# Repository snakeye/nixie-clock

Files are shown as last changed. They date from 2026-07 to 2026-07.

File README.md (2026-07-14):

# Nixie Clock

An ESP32-C3 powered Nixie clock built around custom KiCad hardware and Arduino firmware.

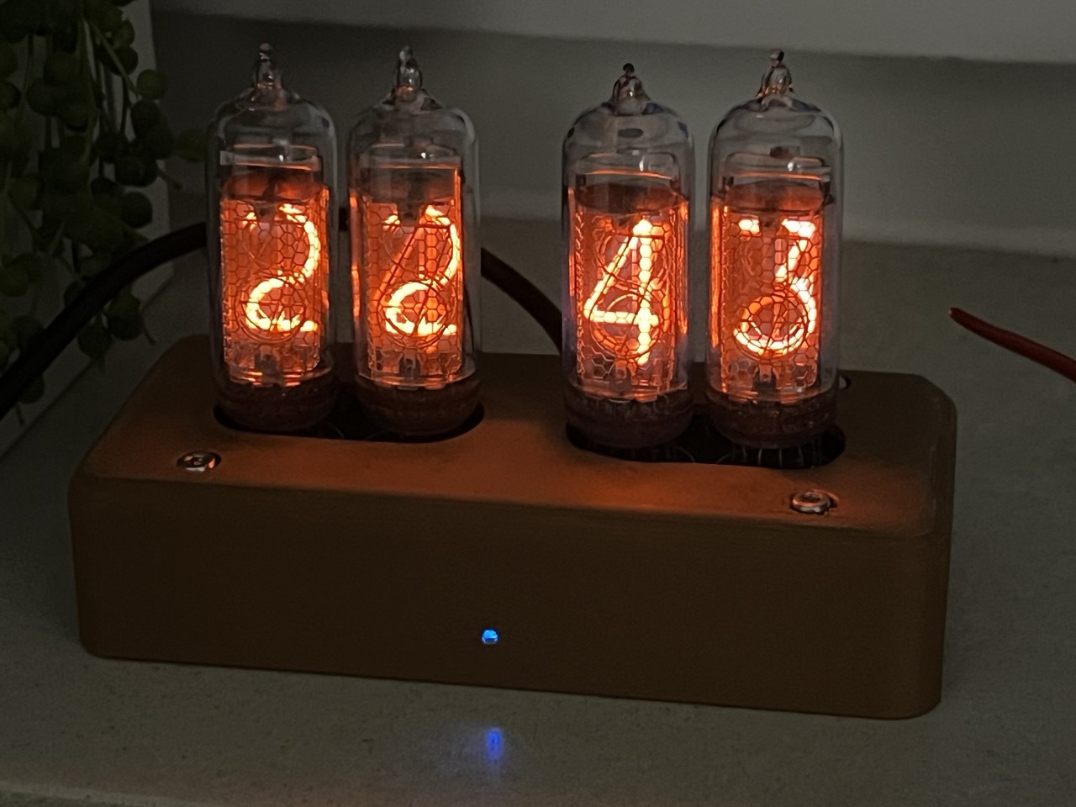
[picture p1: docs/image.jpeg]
Assembled Nixie clock


## Boards

### Main board

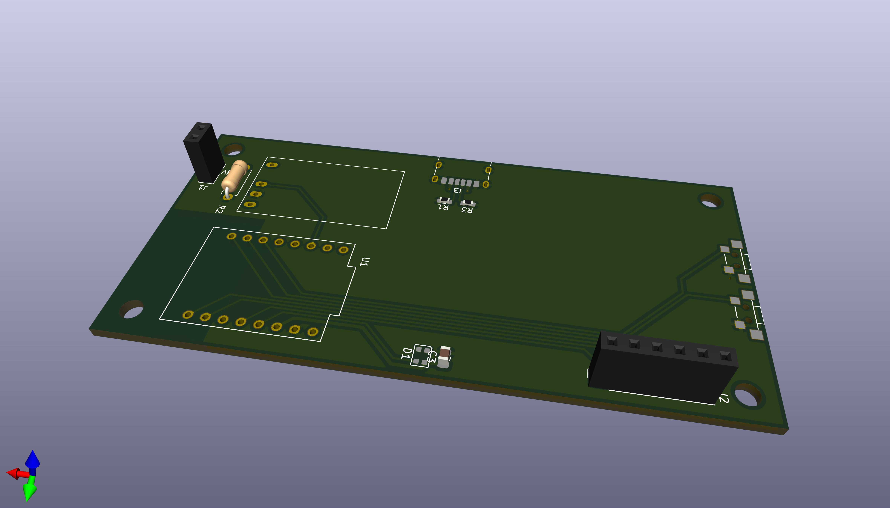
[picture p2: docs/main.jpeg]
Main board in KiCad


### Indicator board

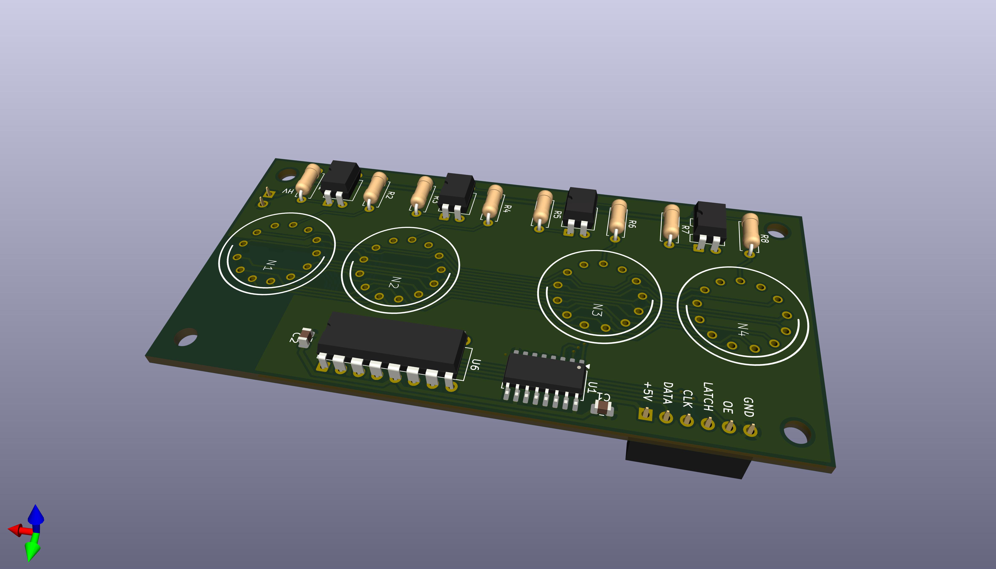
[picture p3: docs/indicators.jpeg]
Indicator board in KiCad


## What this is

This repository contains the hardware and firmware for a four-digit Nixie clock.
It uses Wi-Fi to sync time from NTP, drives the tubes with a multiplexed display stage, and keeps the high-voltage supply disabled until the clock has a valid time.

## Features

- Wi-Fi time sync via NTP
- Automatic high-voltage safety control
- OTA firmware updates
- Manual cathode cleaning from a button long-press
- Automatic daily cathode cleaning at midnight
- KiCad hardware for the main clock board and indicator board

## Key components

- IN-14 Nixie tubes
- 155ИД1 high-voltage digit driver
- ESP32-C3 SuperMini module
- 74HC595 shift register
- TLP627 optocouplers
- Nixie Tube Boost Converter module
- WS2812B RGB status LED
- USB-C power input
- Two push buttons

### High-voltage boost module

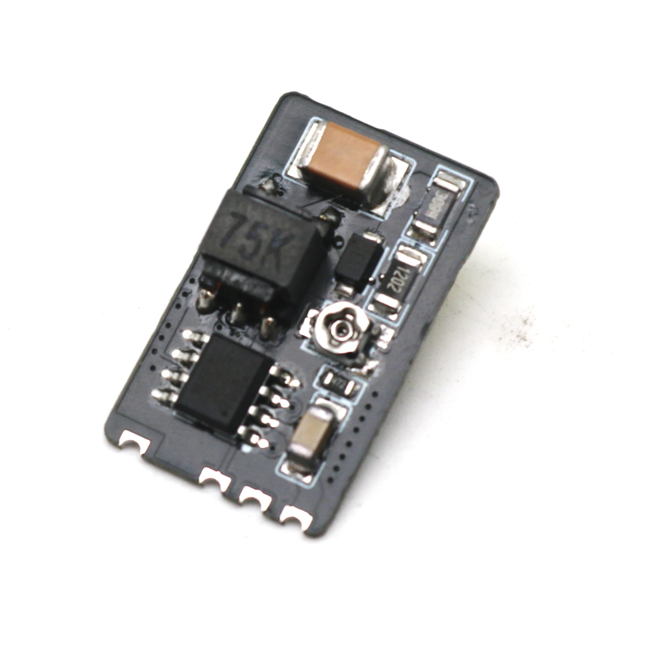
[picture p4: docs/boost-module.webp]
Boost converter module used in the build


I've used this particular module found on AliExpress. It features voltage adjustment. Other modules should also work, but they'll require proper wiring. 

## How it works

The firmware boots in a safe state with the display blanked and the high-voltage rail off.
After Wi-Fi connects and NTP provides a valid time, the clock enables the high-voltage section and starts showing the current time.

When a successful sync happens, the firmware opens a short OTA maintenance window. If an upload starts, the high-voltage rail is disabled while the update is in progress.

Button 1 has a long-press action that starts cathode cleaning manually. The same cleaning routine also runs automatically once per day when the clock reaches midnight.

## Repository layout

- `firmware/` - PlatformIO project for the ESP32-C3
- `hardware/main/` - main KiCad project for the clock board
- `hardware/indicators/` - indicator-board KiCad project
- `docs/` - photos and other documentation assets

## Firmware setup

1. Open `firmware/` in PlatformIO or your preferred VS Code setup.
2. Copy `firmware/src/config.h.example` to `firmware/src/config.h`.
3. Fill in your Wi-Fi SSID and password.
4. Build and upload the `esp32c3` environment.

The firmware is configured for the `esp32-c3-devkitm-1` board.

## Notes

- The clock currently uses a CET/CEST timezone definition in firmware.
- The firmware hostname is `nixie-clock`.
- `firmware/src/config.h` is ignored by Git so local Wi-Fi credentials stay machine-specific.

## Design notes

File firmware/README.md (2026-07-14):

# Nixie Clock Firmware

Firmware for the ESP32-based nixie clock.

## How it works

- On boot the firmware forces the outputs into a safe state.
- It connects to WiFi, configures NTP, and waits for valid time.
- Once time is valid, high voltage is enabled and the display starts multiplexing `HH:MM`.
- WiFi is shut down after sync unless the OTA maintenance window is active.
- During OTA the display is blanked and high voltage stays off.

## Main pieces

- `ClockTime` handles WiFi, NTP, timezone, and time validity.
- `NixieDisplay` owns the display buffer and multiplexing.
- `NixieSafetyController` keeps display and high voltage changes safe.
- `ClockDisplay` updates the shown time once per minute.
- `StatusLed` shows boot, waiting, sync, and OTA states.
- `OtaMaintenance` opens a short OTA window after sync.
- `CathodeCleaning` runs the anti-poisoning cycle at midnight and on long press.

## Controls

- Button 1 long press starts cathode cleaning.

## Configuration

- WiFi credentials currently live in `src/config.h`.
- Debug logging is enabled with the `DEBUG_LOG` build flag.

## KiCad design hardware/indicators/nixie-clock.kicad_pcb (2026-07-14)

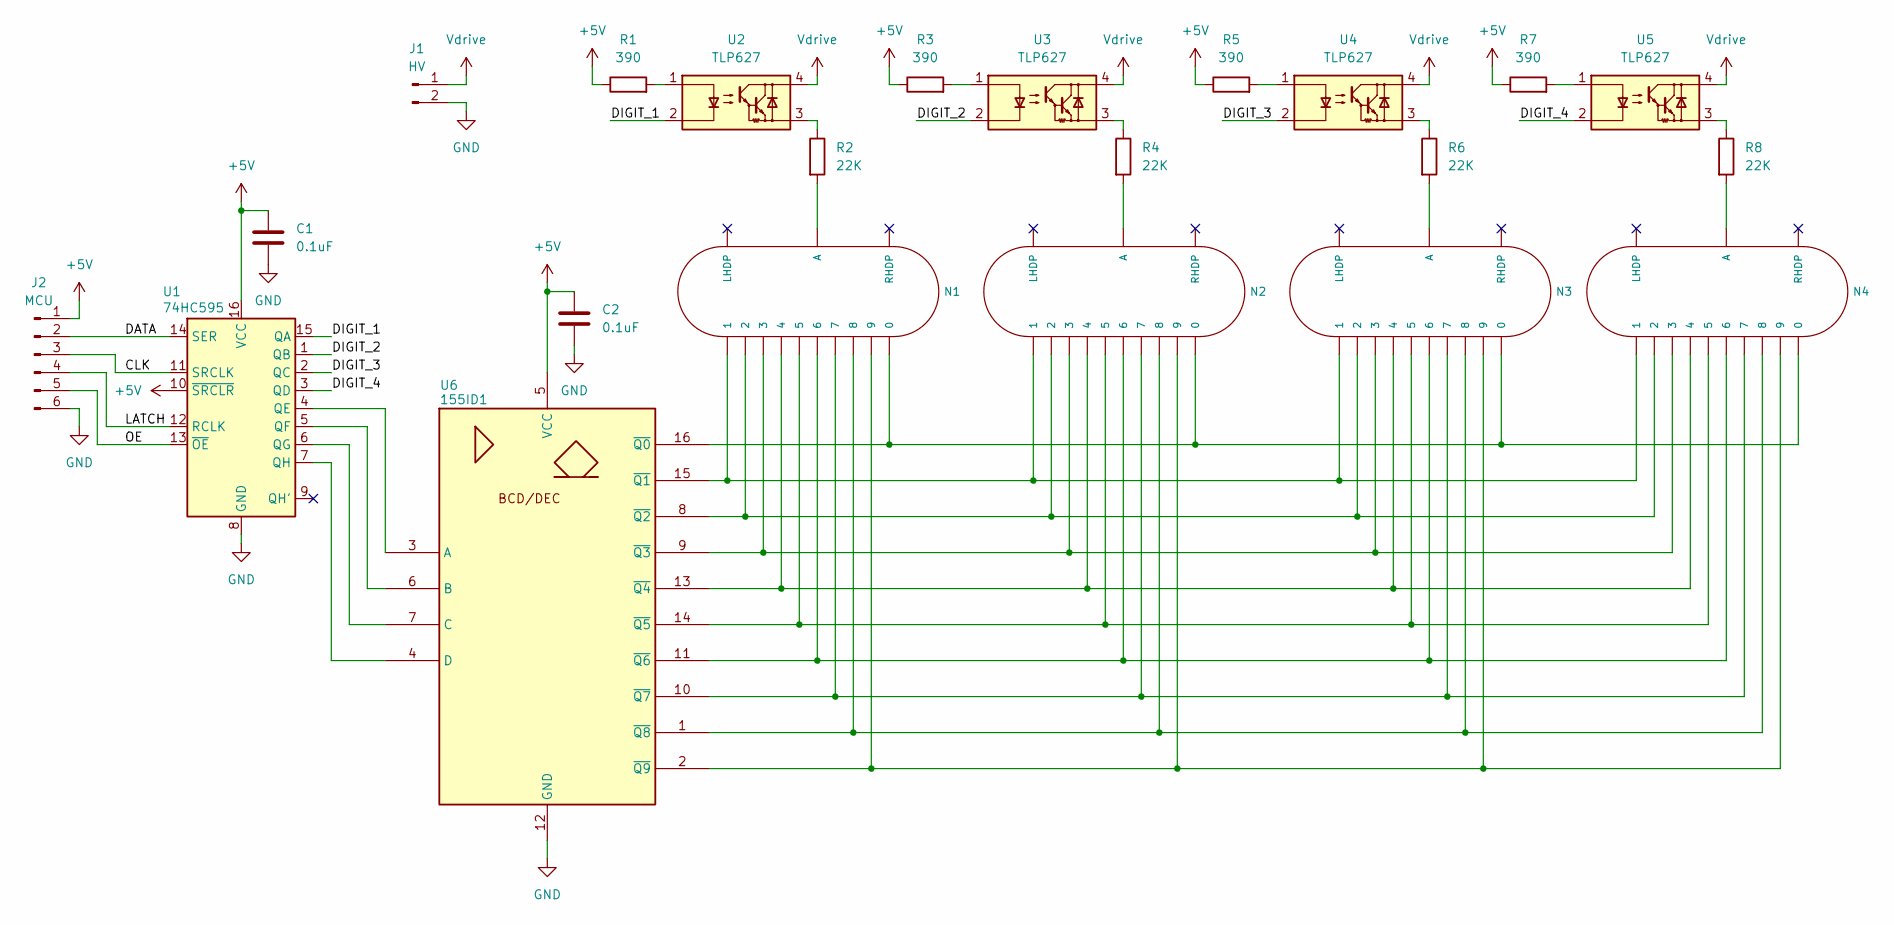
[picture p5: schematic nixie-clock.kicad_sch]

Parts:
C1, C2: 0.1uF; C_0805_2012Metric
J1: HV; PinSocket_1x02_P2.54mm_Vertical
J2: MCU; PinSocket_1x06_P2.54mm_Vertical
N1, N2, N3, N4: IN-14; nixies-us-IN-14
R1, R3, R5, R7: 390; R_Axial_DIN0207_L6.3mm_D2.5mm_P7.62mm_Horizontal
R2, R4, R6, R8: 22K; R_Axial_DIN0207_L6.3mm_D2.5mm_P7.62mm_Horizontal
U1: 74HC595; SOP-16_4.4x10.4mm_P1.27mm
U2, U3, U4, U5: TLP627; DIP-4_W7.62mm
U6: 155ID1; DIP-16_W7.62mm

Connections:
+5V: C1.1, C2.1, J2.1, R1.1, R3.1, R5.1, R7.1, U1.10 (~SRCLR), U1.16 (VCC), U6.5 (VCC)
/CLK: J2.3, U1.11 (SRCLK)
/DATA: J2.2, U1.14 (SER)
/DIGIT_1: U1.15 (QA), U2.2
/DIGIT_2: U1.1 (QB), U3.2
/DIGIT_3: U1.2 (QC), U4.2
/DIGIT_4: U1.3 (QD), U5.2
/LATCH: J2.4, U1.12 (RCLK)
/OE: J2.5, U1.13 (~OE)
GND: C1.2, C2.2, J1.2, J2.6, U1.8 (GND), U6.12 (GND)
unnamed: N1.A, R2.2
unnamed: N2.A, R4.2
unnamed: N3.A, R6.2
unnamed: N4.A, R8.2
unnamed: R1.2, U2.1
unnamed: R2.1, U2.3
unnamed: R3.2, U3.1
unnamed: R4.1, U3.3
unnamed: R5.2, U4.1
unnamed: R6.1, U4.3
unnamed: R7.2, U5.1
unnamed: R8.1, U5.3
unnamed: U1.4 (QE), U6.3 (A)
unnamed: U1.5 (QF), U6.6 (B)
unnamed: U1.6 (QG), U6.7 (C)
unnamed: U1.7 (QH), U6.4 (D)
unnamed: N1.0, N2.0, N3.0, N4.0, U6.16 (~Q0)
unnamed: N1.1, N2.1, N3.1, N4.1, U6.15 (~Q1)
unnamed: N1.2, N2.2, N3.2, N4.2, U6.8 (~Q2)
unnamed: N1.3, N2.3, N3.3, N4.3, U6.9 (~Q3)
unnamed: N1.4, N2.4, N3.4, N4.4, U6.13 (~Q4)
unnamed: N1.5, N2.5, N3.5, N4.5, U6.14 (~Q5)
unnamed: N1.6, N2.6, N3.6, N4.6, U6.11 (~Q6)
unnamed: N1.7, N2.7, N3.7, N4.7, U6.10 (~Q7)
unnamed: N1.8, N2.8, N3.8, N4.8, U6.1 (~Q8)
unnamed: N1.9, N2.9, N3.9, N4.9, U6.2 (~Q9)
Vdrive: J1.1, U2.4, U3.4, U4.4, U5.4

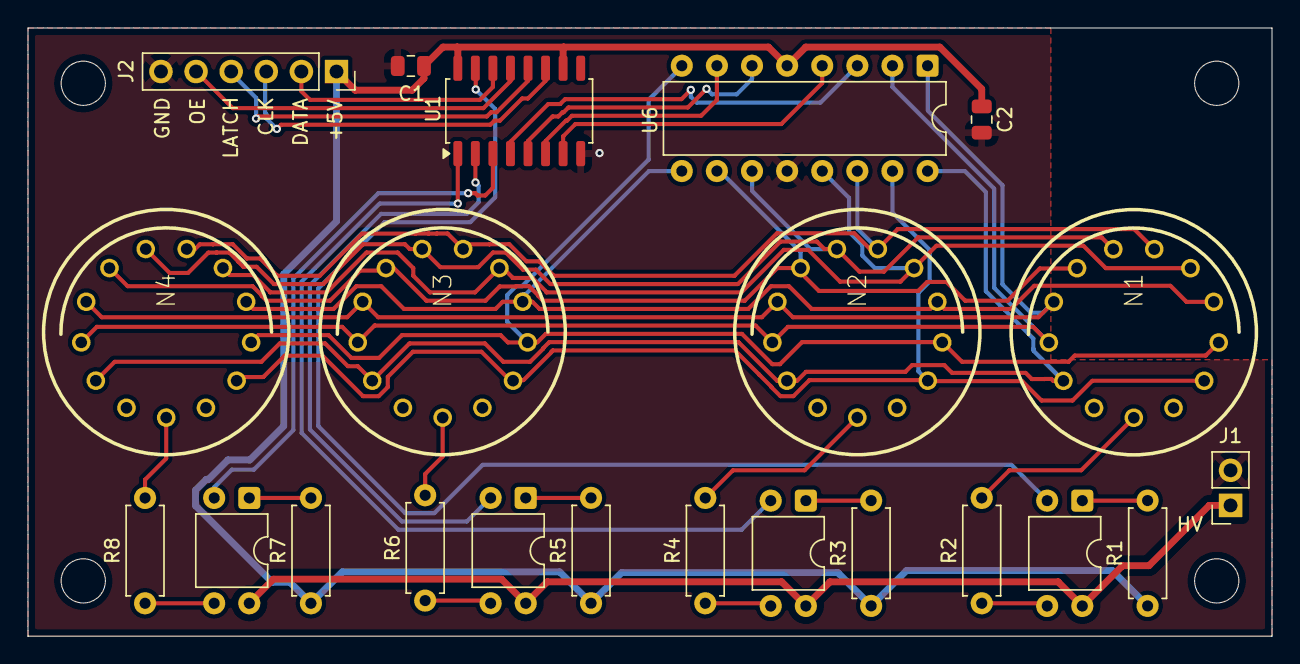
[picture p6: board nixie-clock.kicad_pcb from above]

Board: 2 copper layers, 90.0 x 44.0 mm, 22 parts (0 on the bottom side), 37 nets.

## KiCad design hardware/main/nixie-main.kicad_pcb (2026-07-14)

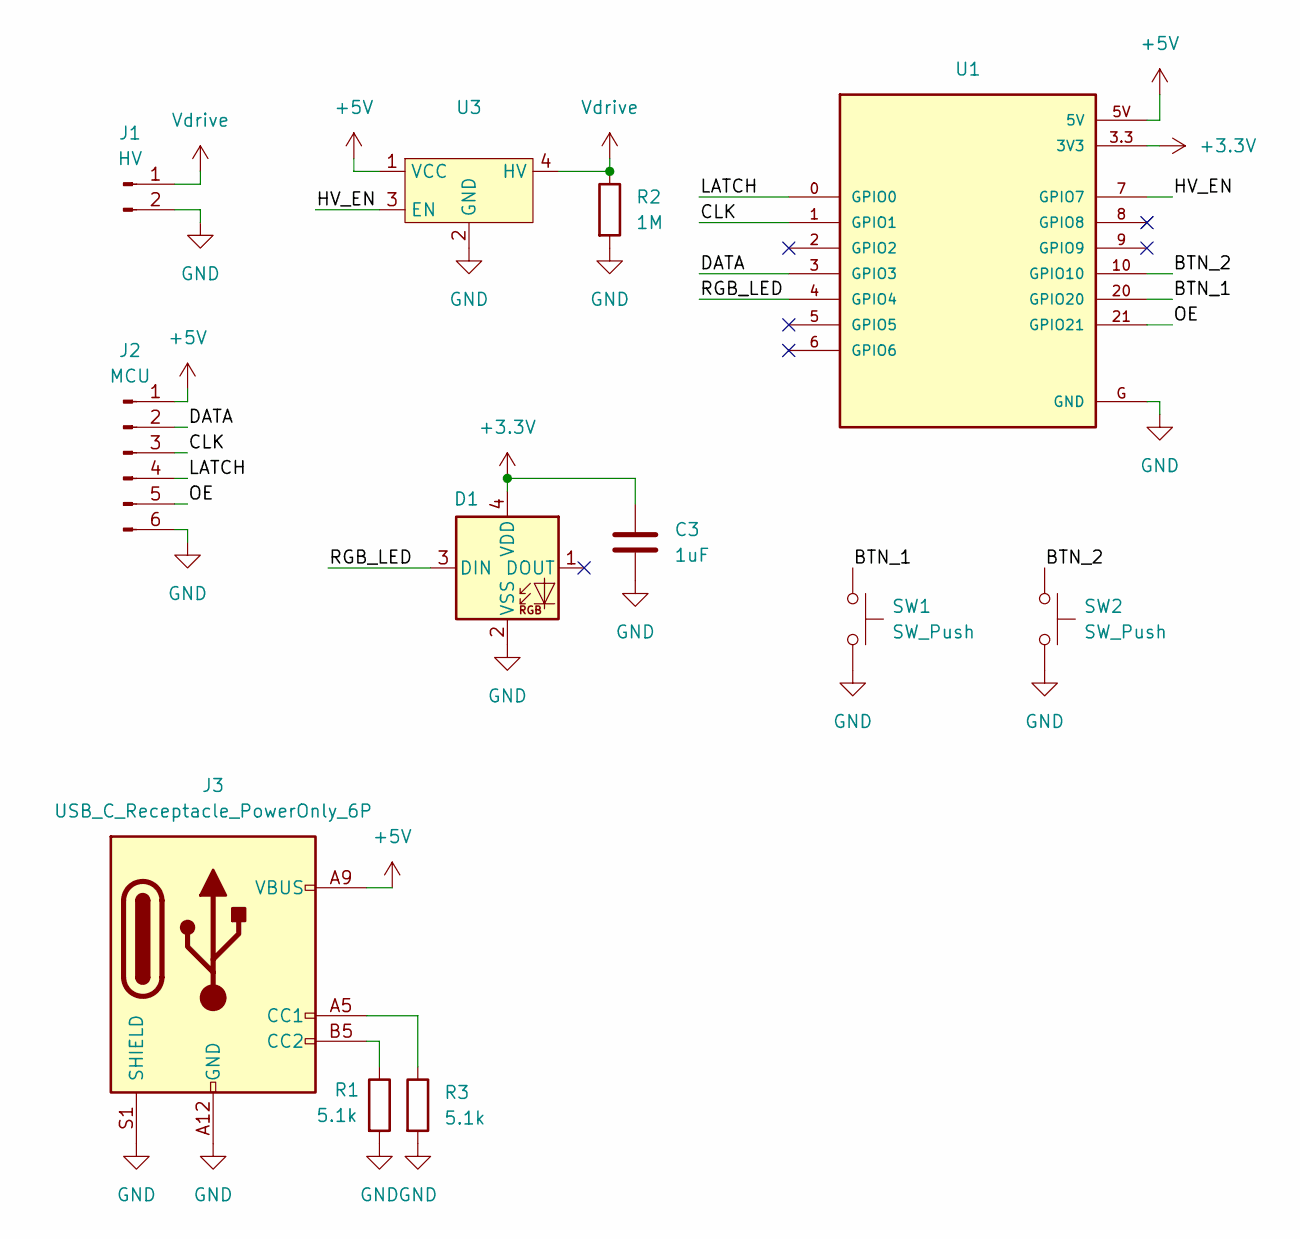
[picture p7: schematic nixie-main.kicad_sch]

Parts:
C3: 1uF; C_0805_2012Metric
D1: WS2812B-2020; LED_WS2812B-2020_PLCC4_2.0x2.0mm
J1: HV; PinSocket_1x02_P2.54mm_Vertical
J2: MCU; PinSocket_1x06_P2.54mm_Vertical
J3: USB_C_Receptacle_PowerOnly_6P; USB_C_Receptacle_HRO_TYPE-C-31-M-17
R1, R3: 5.1k; R_0603_1608Metric
R2: 1M; R_Axial_DIN0207_L6.3mm_D2.5mm_P7.62mm_Horizontal
SW1, SW2: SW_Push; BUTTON
U1: ESP32-C3_SUPERMINI; MODULE_ESP32-C3_SUPERMINI_TH
U3: SIP-5

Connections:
+3.3V: C3.1, D1.4 (VDD), U1.3.3 (3V3)
+5V: J2.1, J3.A9 (VBUS), J3.B9 (VBUS), U1.5V, U3.1 (VCC)
/BTN_1: SW1.1, U1.20 (GPIO20)
/BTN_2: SW2.1, U1.10 (GPIO10)
/CLK: J2.3, U1.1 (GPIO1)
/DATA: J2.2, U1.3 (GPIO3)
/HV_EN: U1.7 (GPIO7), U3.3 (EN)
/LATCH: J2.4, U1.0 (GPIO0)
/OE: J2.5, U1.21 (GPIO21)
/RGB_LED: D1.3 (DIN), U1.4 (GPIO4)
GND: C3.2, D1.2 (VSS), J1.2, J2.6, J3.A12 (GND), J3.B12 (GND), J3.S1 (SHIELD), R1.2, R2.2, R3.2, SW1.2, SW2.2, U1.G (GND), U3.2 (GND)
unnamed: J3.A5 (CC1), R3.1
unnamed: J3.B5 (CC2), R1.1
Vdrive: J1.1, R2.1, U3.4 (HV)

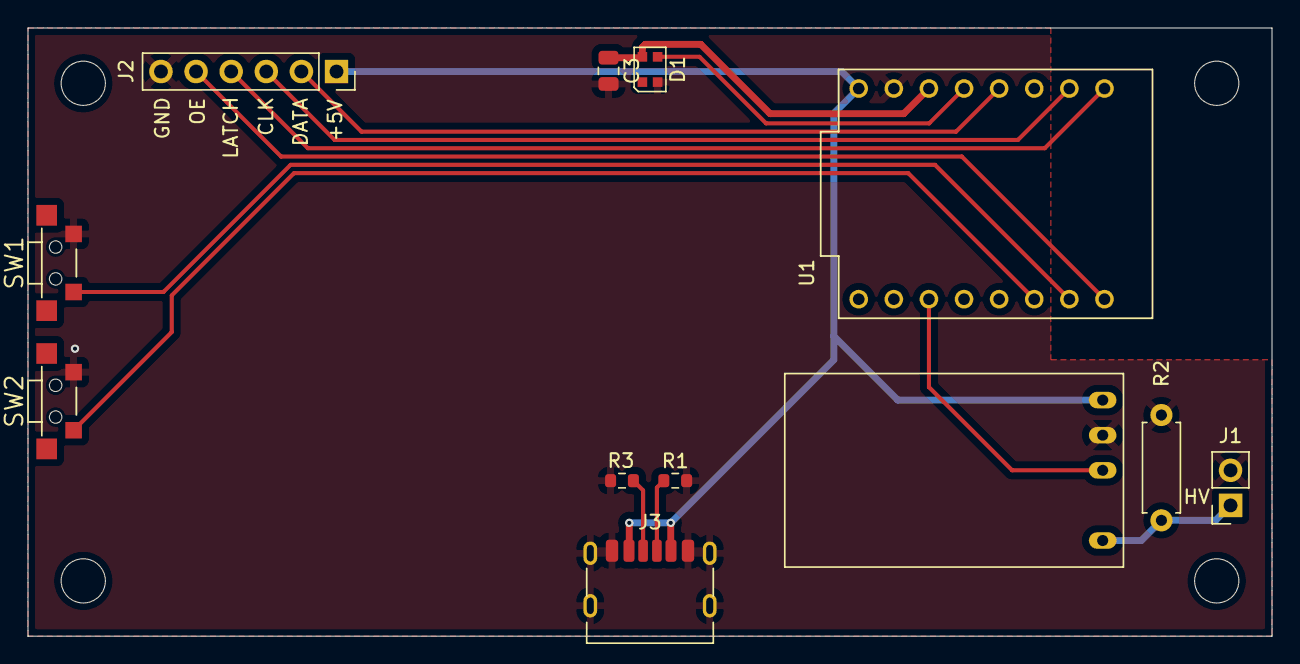
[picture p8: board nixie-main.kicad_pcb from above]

Board: 2 copper layers, 90.0 x 44.0 mm, 12 parts (0 on the bottom side), 14 nets.

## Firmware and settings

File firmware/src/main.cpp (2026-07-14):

#include <OneButton.h>

#include "app_shared.h"
#include "app_state.h"
#include "button_actions.h"
#include "cathode_cleaning.h"
#include "clock_time.h"
#include "debug.h"
#include "ota_maintenance.h"
#include "power_policy.h"
#include "status_led.h"
#include "app_mode.h"

OneButton button1;
OneButton button2;

void setup()
{
    Debug::begin();

    // Preload safe output latch levels before switching GPIOs to OUTPUT.
    // This reduces startup glitches while ESP32 takes ownership of the pins.
    digitalWrite(Pins::ShiftRegisterOutputEnable, Levels::ShiftRegisterOutputDisabled);
    digitalWrite(Pins::HighVoltageEnable, Levels::HighVoltageDisabled);
    digitalWrite(Pins::ShiftRegisterLatch, LOW);
    digitalWrite(Pins::ShiftRegisterClock, LOW);
    digitalWrite(Pins::ShiftRegisterData, LOW);

    pinMode(Pins::StatusLed, OUTPUT);
    pinMode(Pins::ShiftRegisterOutputEnable, OUTPUT);
    pinMode(Pins::HighVoltageEnable, OUTPUT);
    pinMode(Pins::ShiftRegisterLatch, OUTPUT);
    pinMode(Pins::ShiftRegisterClock, OUTPUT);
    pinMode(Pins::ShiftRegisterData, OUTPUT);

    safety.beginSafe();

    button1.setup(Pins::Button1, INPUT_PULLUP, true);
    button2.setup(Pins::Button2, INPUT_PULLUP, true);

    button1.setDebounceMs(50);
    button2.setDebounceMs(50);
    button1.setPressMs(800);
    button2.setPressMs(800);

    button1.attachLongPressStart(onButton1LongPressStart);

    ClockTime::begin();

    StatusLed::startBootWink();
}

void loop()
{
    button1.tick();
    button2.tick();
    ClockTime::update();

    if (ClockTime::consumeJustSynced())
    {
        StatusLed::blinkSyncSuccess();
        OtaMaintenance::beginWindow();
    }

    OtaMaintenance::update();
    updateHighVoltagePolicy();
    CathodeCleaning::update();
    AppMode::update();
}

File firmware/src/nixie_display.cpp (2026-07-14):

#include "nixie_display.h"

#include "debug.h"

void NixieDisplay::beginSafe()
{
    disableDisplay();
    blank();
    Debug::log("[nixie] display safe blank");
}

void NixieDisplay::enableDisplay()
{
    // 74HC595 OE is active-low.
    digitalWrite(Pins::ShiftRegisterOutputEnable, Levels::ShiftRegisterOutputEnabled);
}

void NixieDisplay::disableDisplay()
{
    // 74HC595 OE is active-low.
    digitalWrite(Pins::ShiftRegisterOutputEnable, Levels::ShiftRegisterOutputDisabled);
}

void NixieDisplay::blank()
{
    stopMultiplexing();
    writeRawChecked(AllAnodesDisabledMask);
}

void NixieDisplay::showTime(uint8_t hours, uint8_t minutes, uint8_t seconds)
{
    (void)seconds;

    if (hours > 23 || minutes > 59)
    {
        return;
    }

    displayDigits[0] = hours < 10 ? BlankDigit : hours / 10;
    displayDigits[1] = hours % 10;
    displayDigits[2] = minutes / 10;
    displayDigits[3] = minutes % 10;
    displayBufferValid = true;

    if (!multiplexEnabled)
    {
        startMultiplexing();
    }
}

void NixieDisplay::showUniformDigits(uint8_t digit)
{
    if (digit > 9)
    {
        return;
    }

    displayDigits[0] = digit;
    displayDigits[1] = digit;
    displayDigits[2] = digit;
    displayDigits[3] = digit;
    displayBufferValid = true;

    if (!multiplexEnabled)
    {
        startMultiplexing();
    }
}

bool NixieDisplay::isDisplayBufferValid() const
{
    return displayBufferValid;
}

void NixieDisplay::startMultiplexing()
{
    if (!displayBufferValid)
    {
        return;
    }

    multiplexEnabled = true;
    currentMultiplexTube = 0;
    lastMultiplexStepUs = 0;
}

void NixieDisplay::stopMultiplexing()
{
    multiplexEnabled = false;
}

bool NixieDisplay::isMultiplexing() const
{
    return multiplexEnabled;
}

void NixieDisplay::updateMultiplex()
{
    if (!multiplexEnabled || !displayBufferValid)
    {
        return;
    }

    const unsigned long nowUs = micros();
    if (lastMultiplexStepUs != 0 && nowUs - lastMultiplexStepUs < MultiplexSlotUs)
    {
        return;
    }
    lastMultiplexStepUs = nowUs;

    const uint8_t digit = displayDigits[currentMultiplexTube];

    // During blanking all anodes must be actively disabled,
    // but the cathode driver should already be set to the next digit.
    // If blanking uses BCD=0, any residual anode current shows ghost zeroes.
    writeRawChecked(makeBlankingValue(digit), false);
    enableDisplay();
    delayMicroseconds(MultiplexBlankingUs);

    if (writeRawChecked(makeValue(currentMultiplexTube, digit), false))
    {
        delayMicroseconds(MultiplexSettleUs);
        enableDisplay();
    }

    currentMultiplexTube = (currentMultiplexTube + 1) % TubeCount;
}

uint8_t NixieDisplay::anodeBit(uint8_t tubeIndex)
{
    switch (tubeIndex)
    {
    case 0:
        return AnodeBit0;
    case 1:
        return AnodeBit1;
    case 2:
        return AnodeBit2;
    case 3:
        return AnodeBit3;
    default:
        return AnodeBit0;
    }
}

uint8_t NixieDisplay::enabledAnodeCount(uint8_t value)
{
    uint8_t count = 0;

    for (uint8_t i = 0; i < TubeCount; ++i)
    {
        if ((value & (1U << anodeBit(i))) == Levels::AnodeEnabled)
        {
            ++count;
        }
    }

    return count;
}

uint8_t NixieDisplay::digitFromRawValue(uint8_t value)
{
    return (value & DigitMask) >> DigitBit0;
}

bool NixieDisplay::isSafeRawValue(uint8_t value)
{
    const uint8_t activeAnodes = enabledAnodeCount(value);
    const uint8_t digit = digitFromRawValue(value);

    // Safe states:
    // - no active anodes: display blank, any BCD bits are harmless
    // - exactly one active anode with a valid BCD digit 0..9
    if (activeAnodes == 0)
    {
        return true;
    }

    return activeAnodes == 1 && digit <= 9;
}

uint8_t NixieDisplay::makeValue(uint8_t tubeIndex, uint8_t digit)
{
    if (tubeIndex >= TubeCount || digit == BlankDigit || digit > 9)
    {
        return AllAnodesDisabledMask;
    }

    uint8_t value = AllAnodesDisabledMask;

    // Enable exactly one anode by pulling the optocoupler LED cathode low.
    value &= ~(1U << anodeBit(tubeIndex));

    // Put BCD digit on 155ИД1 inputs A..D, connected to 74HC595 QE..QH.
    value |= (digit & 0x0F) << DigitBit0;

    return value;
}

uint8_t NixieDisplay::makeBlankingValue(uint8_t digit)
{
    if (digit == BlankDigit || digit > 9)
    {
        return AllAnodesDisabledMask;
    }

    // Keep all anodes actively disabled while preloading the next cathode digit.
    // This avoids showing BCD=0 during blanking when the previous anode path is still decaying.
    return AllAnodesDisabledMask | ((digit & 0x0F) << DigitBit0);
}

void NixieDisplay::shiftOutRawUnsafe(uint8_t value, bool logWrite)
{
    currentRawValue = value;
    if (logWrite)
    {
        Debug::logRawWritten(value);
    }

    digitalWrite(Pins::ShiftRegisterLatch, LOW);
    digitalWrite(Pins::ShiftRegisterClock, LOW);

    for (int8_t bit = 7; bit >= 0; --bit)
    {
        digitalWrite(Pins::ShiftRegisterData, (value & (1U << bit)) ? HIGH : LOW);
        digitalWrite(Pins::ShiftRegisterClock, HIGH);
        digitalWrite(Pins::ShiftRegisterClock, LOW);
    }

    digitalWrite(Pins::ShiftRegisterLatch, HIGH);
    digitalWrite(Pins::ShiftRegisterLatch, LOW);
}

bool NixieDisplay::writeRawChecked(uint8_t value, bool logWrite)
{
    if (!isSafeRawValue(value))
    {
        Debug::logRawRejected(value);
        disableDisplay();
        shiftOutRawUnsafe(AllAnodesDisabledMask, logWrite);
        return false;
    }

    shiftOutRawUnsafe(value, logWrite);
    return true;
}
